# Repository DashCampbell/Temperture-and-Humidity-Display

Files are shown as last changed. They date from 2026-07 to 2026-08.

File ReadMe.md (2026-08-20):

# Temperature & Humidity Display

A basic PCB displaying the temperature and humidity from a sensor to a OLED screen.

* Uses a STM32 microcontroller with SWD.
* Uses FreeRTOS to run tasks concurrently.
* Uses I2C to communicate with the OLED display and sensor.
* Uses PWM to controll a RGB addressable LED.

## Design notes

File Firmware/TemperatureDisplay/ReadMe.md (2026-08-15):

# Potential Improvements

* Use buck converter to drop battery voltage from 9V to 3.3V, more energy efficient

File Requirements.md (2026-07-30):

# Requirements
## General
- Display the temperature
- Display the humidity
- Have led(s) that change color based on temperature

## Hardware
- A temperature sensor
- A humidity sensor
- At least 5 leds
- An LCD Display
- Use a STM32L432KCUx MCU
- **TODO**: Choose a connection type
- Use SWD

### Future Improvements
- Add a battery

## Firmware
- Read temperature data
- Read humidity data
- Render data in LCD display
- Change led color based on temperature

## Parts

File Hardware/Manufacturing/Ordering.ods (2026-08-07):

Reference | Required Qty | Value | URL | Quantity | Cost | Total Cost | Bought
C1,C2 | 2 | 22u | https://www.digikey.ca/en/products/detail/samsung-electro-mechanics/CL21A226KPCLRNC/5961270 | 4 | $0.40 | $1.60 | X
C3,C10 | 2 | 10n | https://www.digikey.ca/en/products/detail/murata-electronics/GCM188R72A103KA37D/1641655 | 4 | $0.10 | $0.40 | X
C4,C5,C6,C7,C11 | 5 | 100n | https://www.digikey.ca/en/products/detail/kyocera-avx/06035C104KAZ2A/1024797 | 10 | $0.10 | $1.00 | X
C8 | 1 | 4u7 | https://www.digikey.ca/en/products/detail/taiyo-yuden/LMK107BJ475KA-T/1004029 | 2 | $0.15 | $0.30 | X
C9 | 1 | 1u | https://www.digikey.ca/en/products/detail/samsung-electro-mechanics/CL10B105KO8NNNC/3886677 | 2 | $0.10 | $0.20 | X
D1 | 1 | WS2812B | https://www.digikey.ca/en/products/detail/sparkfun-electronics/16347/11630204 | 2 | $0.68 | $1.36 | X
FB1 | 1 | 120R |  |  |  | $0.00
J1 | 1 | Power |  | 0 |  | $0.00
J2 | 1 | SSD1306 Display | https://www.amazon.ca/0-96inch-Module-Display-SSD1306-Driver/dp/B0CPZD1GS2 | 1 | $11.58 | $11.58
J3 | 1 | SWD |  | 0 |  | $0.00
LED1,LED2 | 2 | LTST-C170KGKT | https://www.digikey.ca/en/products/detail/liteon/LTST-C170KGKT/386777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 | 4 | $0.19 | $0.76 | X
R1,R2,R4,R5 | 4 | 10k |  |  |  | $0.00
R3 | 1 | 10k |  |  |  | $0.00
SW1 | 1 | SW_Push |  | 0 |  | $0.00
SW2 | 1 | SW_Nidec_CAS-120A1 | https://www.digikey.ca/en/products/detail/nidec-components/CAS-120TA/341661 | 2 | $1.29 | $2.58 | X
U1 | 1 | AMS1117-3.3 |  | 0 |  | $0.00
U2 | 1 | HDC2010YPAR | https://www.digikey.ca/en/products/detail/texas-instruments/HDC2010YPAR/7561364 | 2 | $1.73 | $3.46 | X
U3 | 1 | STM32L432KCU6 | https://www.digikey.ca/en/products/detail/stmicroelectronics/stm32l432kcu6/6132749 | 2 | $5.75 | $11.50 | X
Y1 | 1 | 8MHz Crystal | https://www.digikey.ca/en/products/detail/abracon-llc/ASE-8-000MHZ-L-C-T/1236874 | 2 | $1.30 | $2.60 | X
 |  |  |  |  | Total Parts Cost: | $37.34
Total Ordering Cost
Digikey | $45.30
Amazon | $16.37
JLCPCB | $27.30
Total: | $88.97

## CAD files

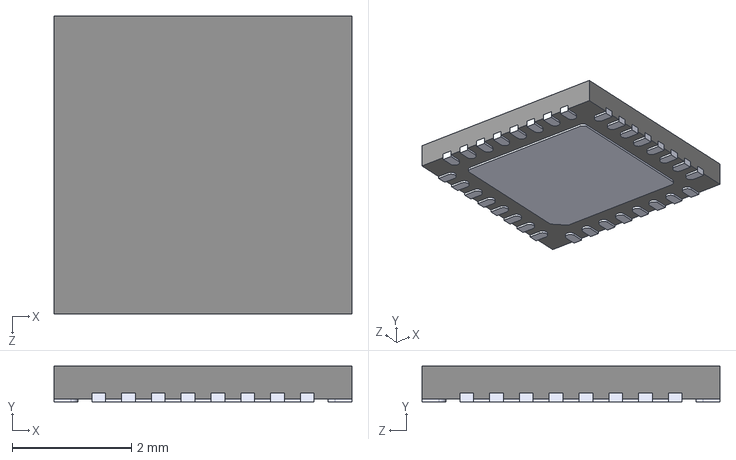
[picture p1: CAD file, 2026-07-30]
Hardware/3D_Models/STM32L432KCU6.step
5.00 x 0.6 x 5.00 mm

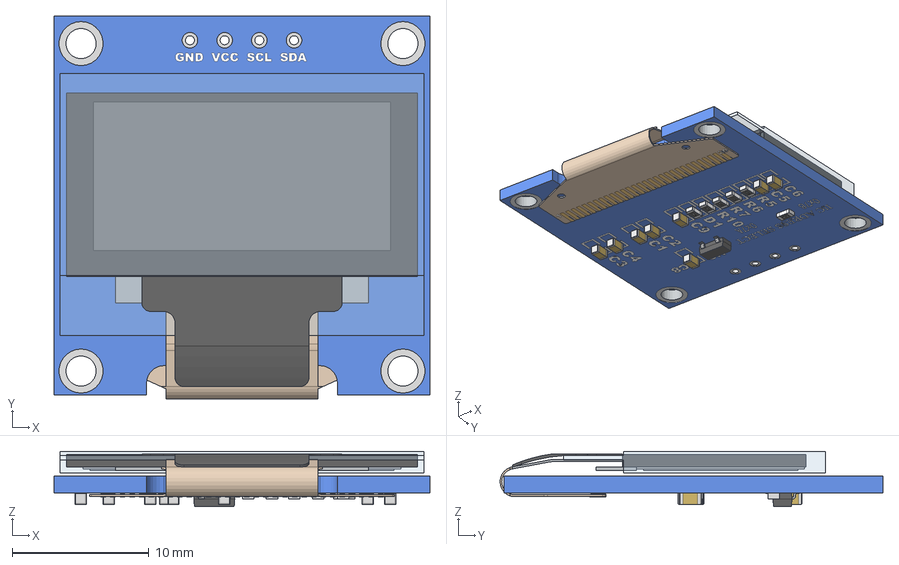
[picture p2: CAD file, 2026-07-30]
Hardware/3D_Models/ER-OLEDM0.96-1-I2C_3D.stp
27.5 x 28.0 x 4.03 mm
0.96 OLED - Board - i2c
0.96 OLED - Glass
0.96 OLED - Flat Reverse
0603 Resistor x 6
SOT-23
0603 Capacitor x 8

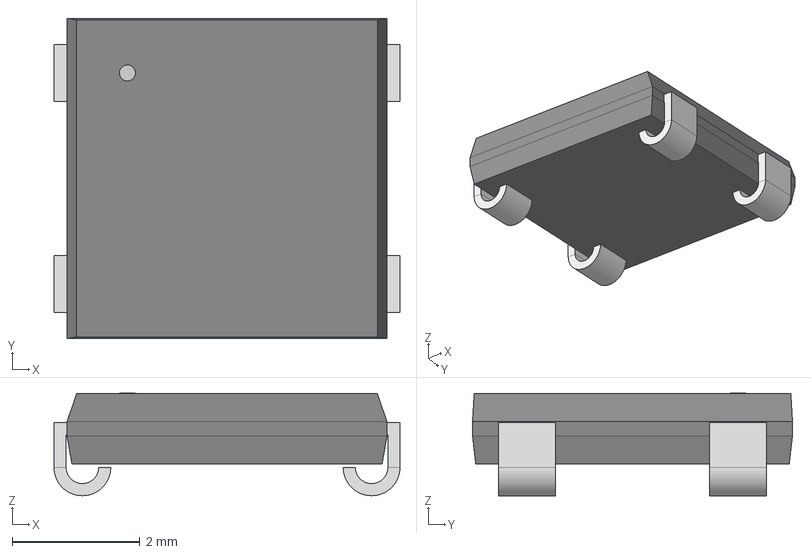
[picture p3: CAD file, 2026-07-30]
Hardware/3D_Models/COM-16347_SPK.step
5.41 x 5.00 x 1.60 mm

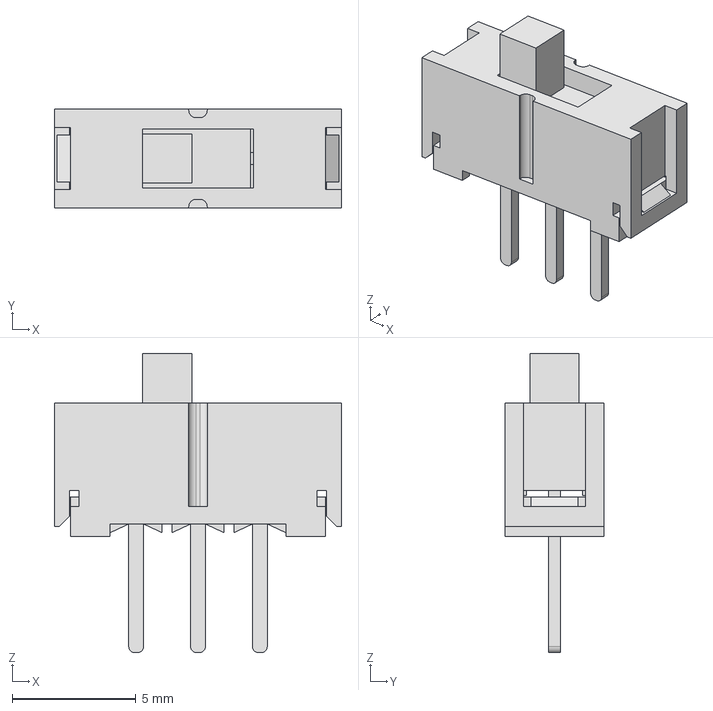
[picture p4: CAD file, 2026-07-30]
Hardware/3D_Models/141_EG1218.stp
11.6 x 4.00 x 12.1 mm

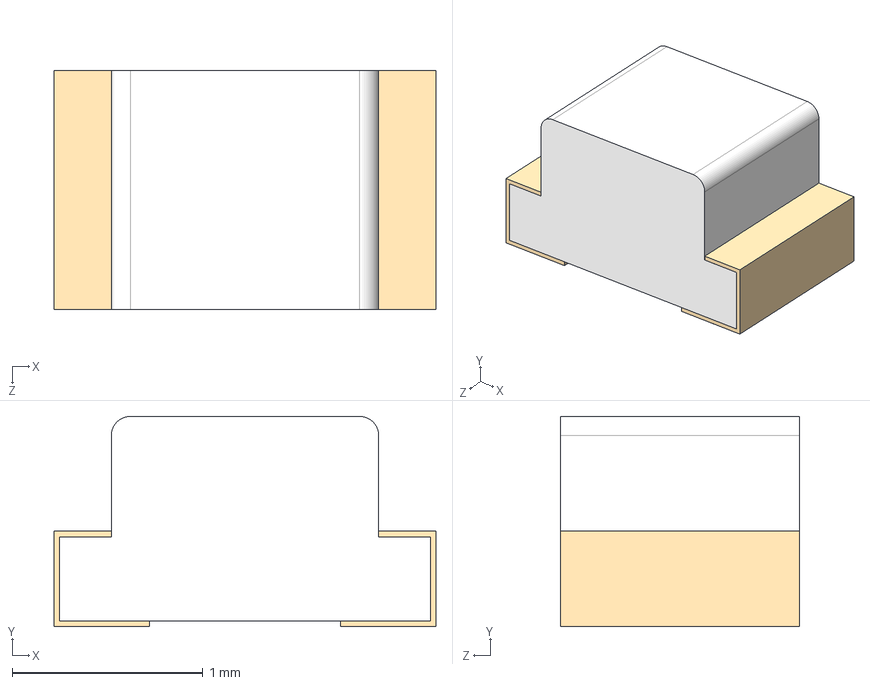
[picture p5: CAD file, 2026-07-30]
Hardware/3D_Models/LTST-C170KGKT.step
2.00 x 1.10 x 1.25 mm

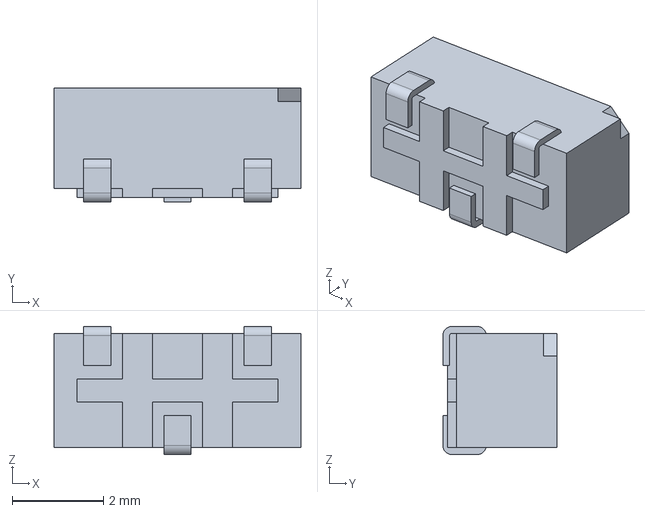
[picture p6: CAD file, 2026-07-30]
Hardware/3D_Models/CAS-120TA.stp
5.40 x 2.50 x 2.80 mm
CAS_c_12A
1 pole_s

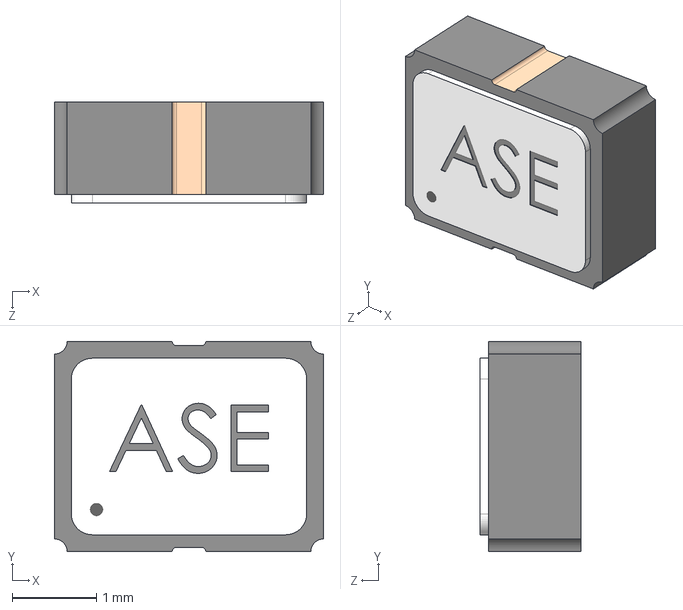
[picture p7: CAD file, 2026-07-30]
Hardware/3D_Models/ASE.STEP
3.20 x 2.50 x 1.20 mm

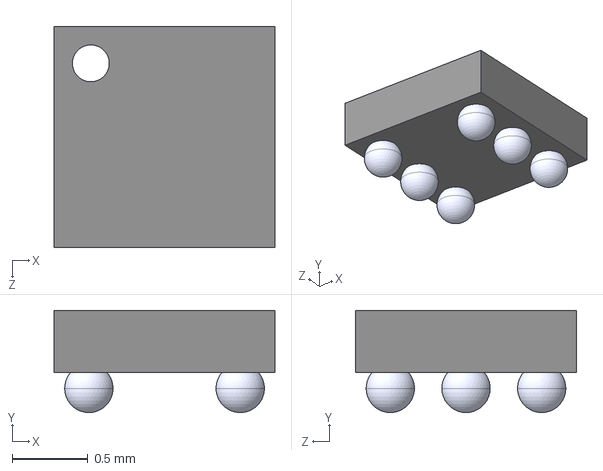
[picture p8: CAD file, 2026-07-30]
Hardware/3D_Models/HDC2010YPAR.step
1.46 x 0.675 x 1.46 mm

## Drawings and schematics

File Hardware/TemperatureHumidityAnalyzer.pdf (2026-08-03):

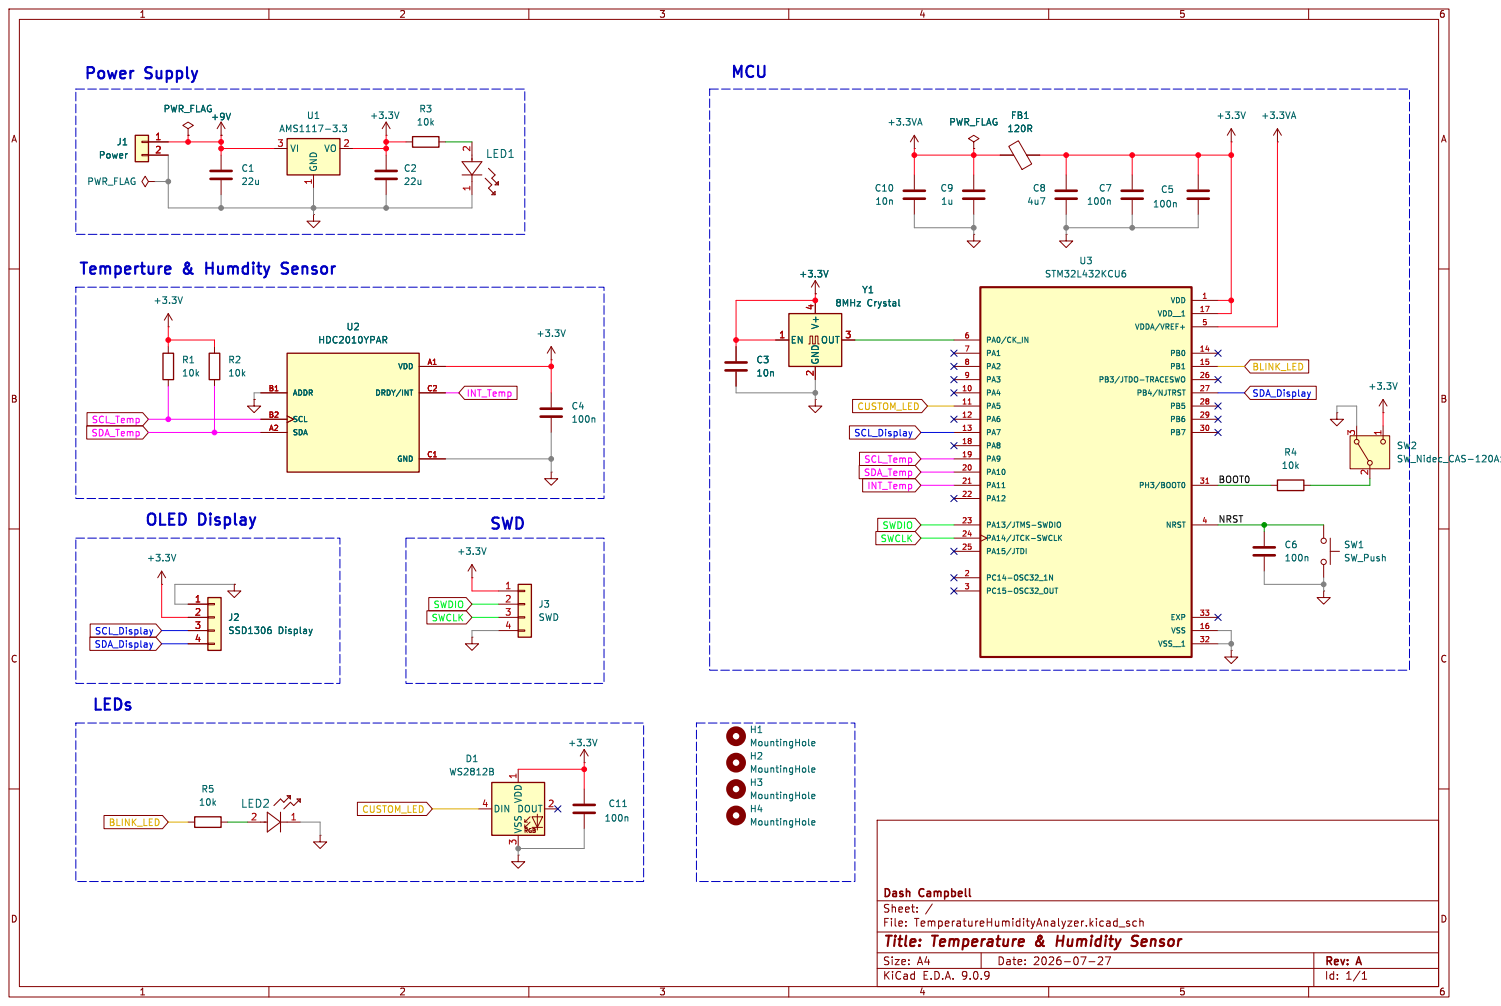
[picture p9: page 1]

Id: 1/1 Title: Temperature & Humidity Sensor File: TemperatureHumidityAnalyzer.kicad_sch Sheet: / Dash Campbell

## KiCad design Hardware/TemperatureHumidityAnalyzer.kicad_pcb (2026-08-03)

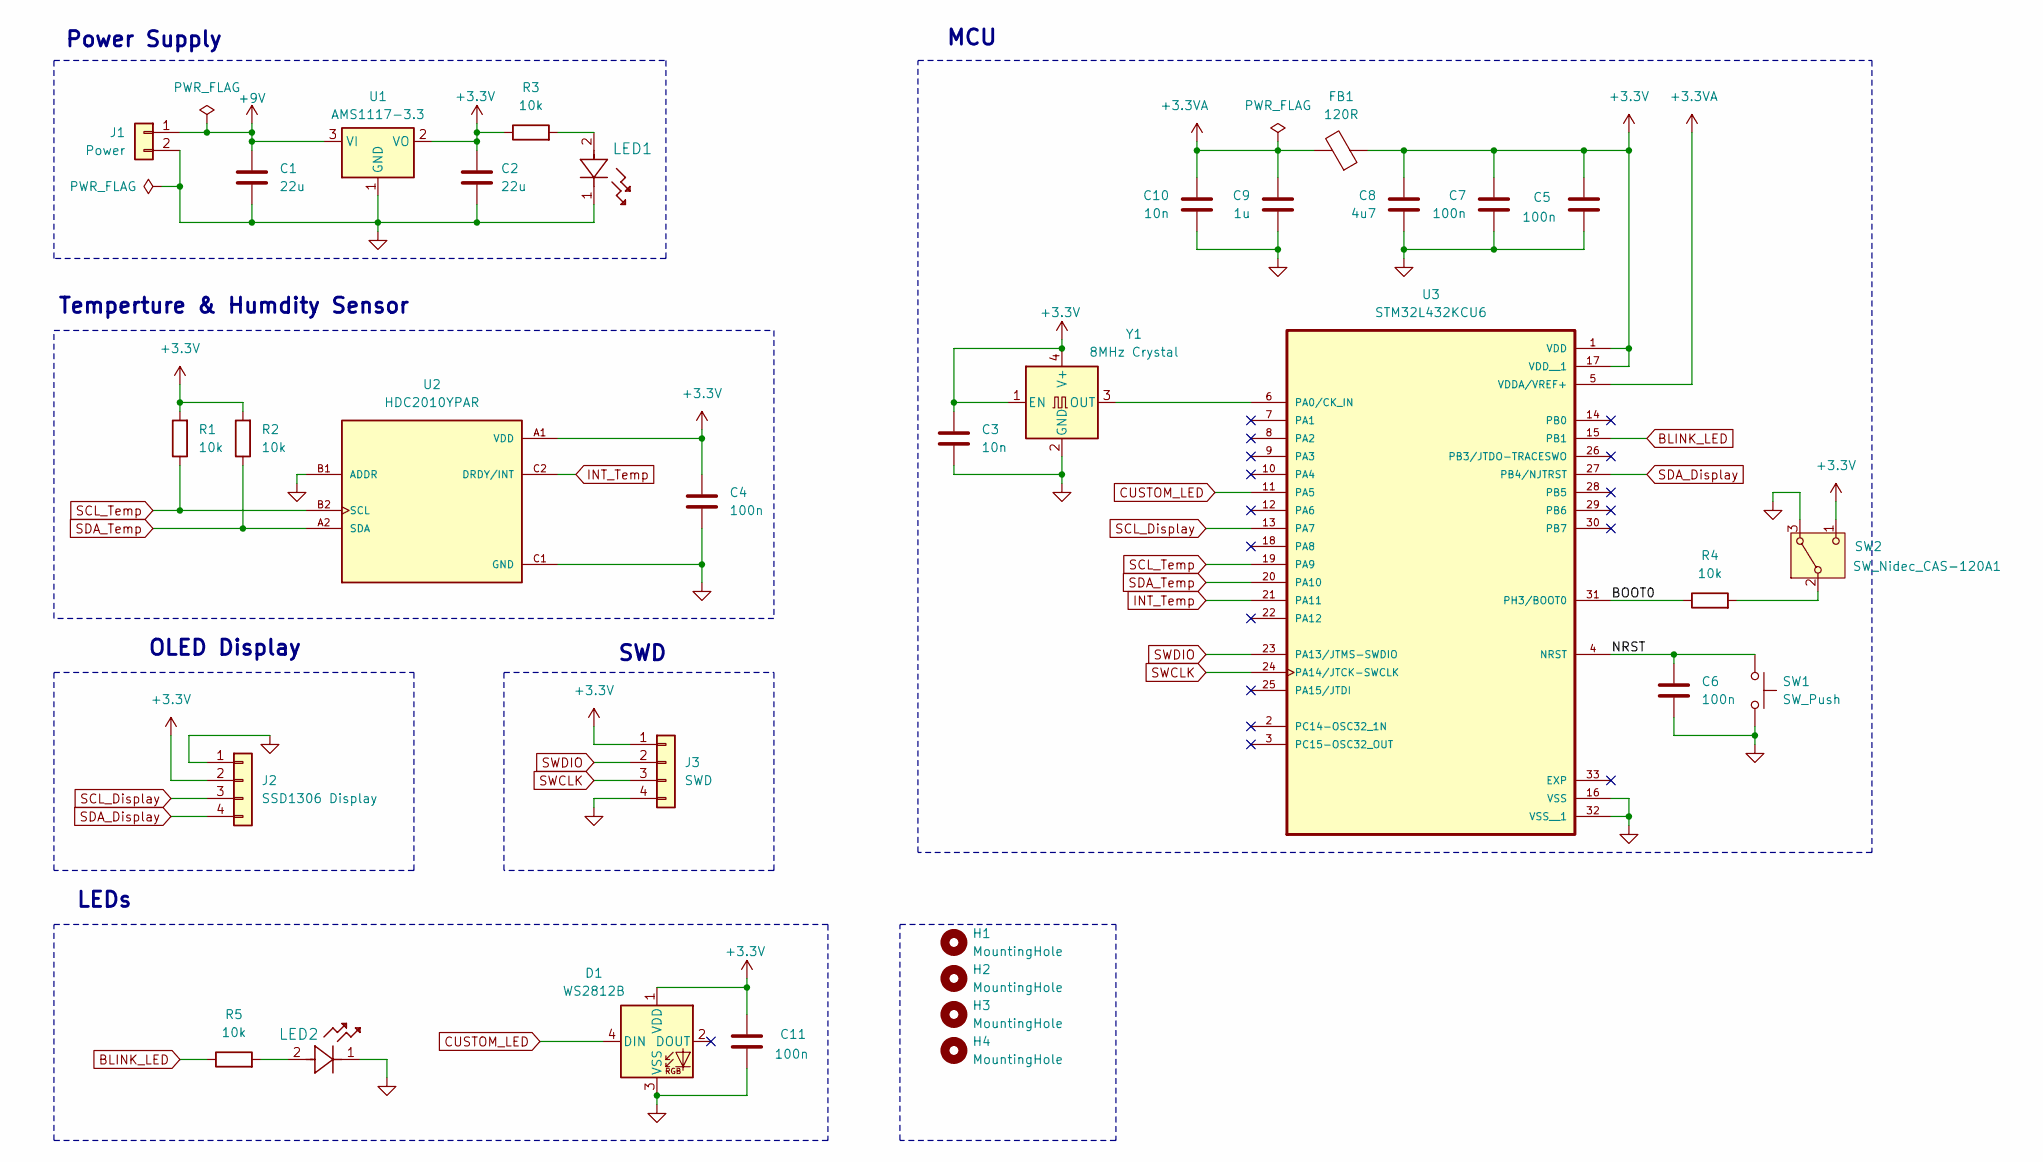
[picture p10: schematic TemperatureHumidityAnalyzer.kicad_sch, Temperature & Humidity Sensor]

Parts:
C1, C2: 22u; C_0805_2012Metric_Pad1.18x1.45mm_HandSolder
C3, C10: 10n; C_0603_1608Metric_Pad1.08x0.95mm_HandSolder
C4, C5, C6, C7, C11: 100n; C_0603_1608Metric_Pad1.08x0.95mm_HandSolder
C8: 4u7; C_0603_1608Metric_Pad1.08x0.95mm_HandSolder
C9: 1u; C_0603_1608Metric_Pad1.08x0.95mm_HandSolder
D1: WS2812B; LED_OPSCO_SK6812_PLCC4_5.0x5.0mm_P3.1mm
FB1: 120R; L_0603_1608Metric_Pad1.05x0.95mm_HandSolder
H1, H2, H3, H4: MountingHole; MountingHole_2.2mm_M2
J1: Power; PinSocket_1x02_P2.54mm_Vertical
J2: SSD1306 Display; SSD1306
J3: SWD; PinHeader_1x04_P2.54mm_Vertical
LED1, LED2: LTST-C170KGKT; LED_LTST-C170KGKT_LTO
R1, R2, R4, R5: 10k; R_0603_1608Metric_Pad0.98x0.95mm_HandSolder
R3: 10k; R_0805_2012Metric_Pad1.20x1.40mm_HandSolder
SW1: SW_Push; SW_PUSH_6mm
SW2: SW_Nidec_CAS-120A1; Nidec_Copal_CAS-120A
U1: AMS1117-3.3; SOT-223-3_TabPin2
U2: HDC2010YPAR; BGA6C100X50P2X3_HDC2010YPAR; PARTREV C
U3: STM32L432KCU6; PARTREV 3
Y1: 8MHz Crystal; Oscillator_SMD_EuroQuartz_XO32-4Pin_3.2x2.5mm

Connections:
+3.3V: C2.1, C3.1, C4.1, C5.1, C7.1, C8.1, C11.1, D1.1 (VDD), FB1.1, J2.2, J3.1, R1.2, R2.2, R3.1, SW2.1 (C), U1.2 (VO), U2.A1 (VDD), U3.1 (VDD), U3.17 (VDD__1), Y1.1 (EN), Y1.4 (V+)
+3.3VA: C9.1, C10.1, FB1.2, U3.5 (VDDA/VREF+)
+9V: C1.1, J1.1, U1.3 (VI)
/BOOT0: R4.1, U3.31 (PH3/BOOT0)
/NRST: C6.1, SW1.1, U3.4 (NRST)
BLINK_LED: R5.1, U3.15 (PB1)
CUSTOM_LED: D1.4 (DIN), U3.11 (PA5)
GND: C1.2, C2.2, C3.2, C4.2, C5.2, C6.2, C7.2, C8.2, C9.2, C10.2, C11.2, D1.3 (VSS), J1.2, J2.1, J3.4, LED1.1, LED2.1, SW1.2, SW2.3 (A), U1.1 (GND), U2.B1 (ADDR), U2.C1 (GND), U3.16 (VSS), U3.32 (VSS__1), Y1.2 (GND)
INT_Temp: U2.C2 (DRDY/INT), U3.21 (PA11)
unnamed: LED1.2, R3.2
unnamed: LED2.2, R5.2
unnamed: R4.2, SW2.2 (B)
unnamed: U3.6 (PA0/CK_IN), Y1.3 (OUT)
SCL_Display: J2.3, U3.13 (PA7)
SCL_Temp: R1.1, U2.B2 (SCL), U3.19 (PA9)
SDA_Display: J2.4, U3.27 (PB4/NJTRST)
SDA_Temp: R2.1, U2.A2 (SDA), U3.20 (PA10)
SWCLK: J3.3, U3.24 (PA14/JTCK-SWCLK)
SWDIO: J3.2, U3.23 (PA13/JTMS-SWDIO)

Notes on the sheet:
OLED Display
Power Supply
SWD
Temperture & Humdity Sensor
LEDs
MCU

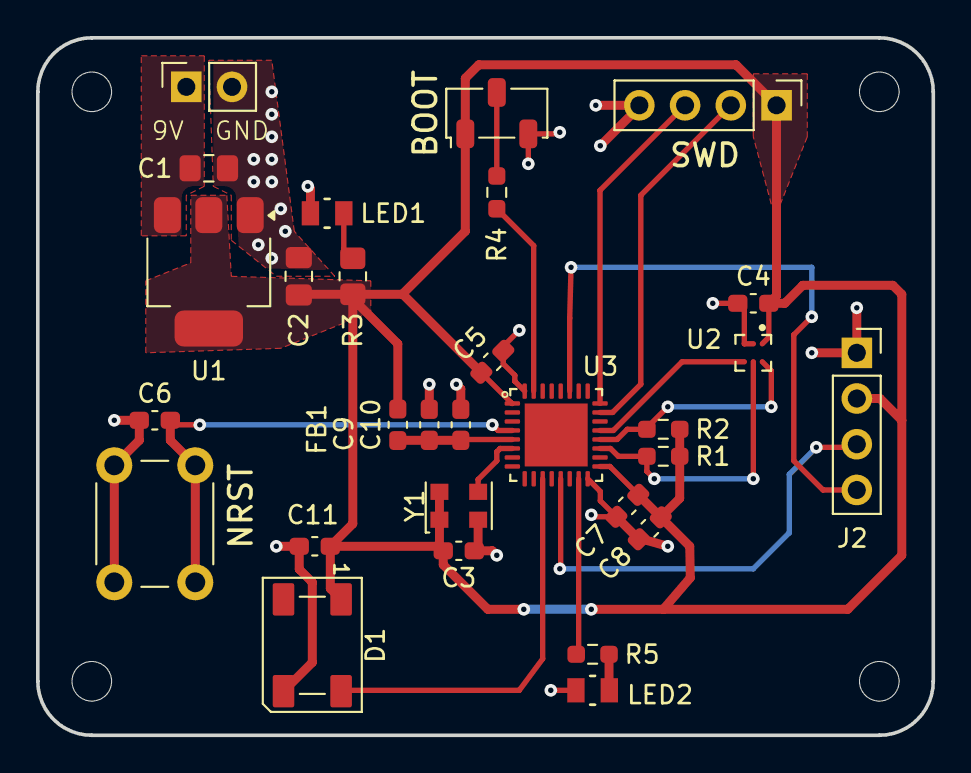
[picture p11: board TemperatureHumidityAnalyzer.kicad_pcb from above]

Board: 2 copper layers, 49.8 x 38.8 mm, 33 parts (0 on the bottom side), 19 nets.

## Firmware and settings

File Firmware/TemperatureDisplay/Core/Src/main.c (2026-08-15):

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
/* Includes ------------------------------------------------------------------*/
#include "main.h"
#include "cmsis_os.h"

/* USER CODE BEGIN Includes */
#include "ssd1306_fonts.h"
#include "ssd1306.h"
#include "hdc2010.h"
#include "ws2812b.h"
#include <stdio.h>
// I2C api
// https://dev.st.com/stm32cube-docs/stm32u5-hal2/2.0.0-beta.1.1/docs/drivers/hal_drivers/i2c/hal_i2c_apis.html

/* USER CODE END Includes */

typedef StaticTask_t osStaticThreadDef_t;
typedef StaticQueue_t osStaticMessageQDef_t;
typedef StaticEventGroup_t osStaticEventGroupDef_t;
/* USER CODE BEGIN PD */

// FreeRTOS Events
#define SENSOR_READY 0x01

/* USER CODE END PD */

I2C_HandleTypeDef hi2c1;
I2C_HandleTypeDef hi2c3;

TIM_HandleTypeDef htim2;
DMA_HandleTypeDef hdma_tim2_ch1;

/* Definitions for defaultTask */
osThreadId_t defaultTaskHandle;
uint32_t defaultTaskBuffer[ 128 ];
osStaticThreadDef_t defaultTaskControlBlock;
const osThreadAttr_t defaultTask_attributes = {
  .name = "defaultTask",
  .cb_mem = &defaultTaskControlBlock,
  .cb_size = sizeof(defaultTaskControlBlock),
  .stack_mem = &defaultTaskBuffer[0],
  .stack_size = sizeof(defaultTaskBuffer),
  .priority = (osPriority_t) osPriorityNormal,
};
/* Definitions for sensorTask */
osThreadId_t sensorTaskHandle;
uint32_t sensorTaskBuffer[ 512 ];
osStaticThreadDef_t sensorTaskControlBlock;
const osThreadAttr_t sensorTask_attributes = {
  .name = "sensorTask",
  .cb_mem = &sensorTaskControlBlock,
  .cb_size = sizeof(sensorTaskControlBlock),
  .stack_mem = &sensorTaskBuffer[0],
  .stack_size = sizeof(sensorTaskBuffer),
  .priority = (osPriority_t) osPriorityNormal,
};
/* Definitions for displayTask */
osThreadId_t displayTaskHandle;
uint32_t displayTaskBuffer[ 3000 ];
osStaticThreadDef_t displayTaskControlBlock;
const osThreadAttr_t displayTask_attributes = {
  .name = "displayTask",
  .cb_mem = &displayTaskControlBlock,
  .cb_size = sizeof(displayTaskControlBlock),
  .stack_mem = &displayTaskBuffer[0],
  .stack_size = sizeof(displayTaskBuffer),
  .priority = (osPriority_t) osPriorityBelowNormal,
};
/* Definitions for ledTask */
osThreadId_t ledTaskHandle;
uint32_t ledTaskBuffer[ 256 ];
osStaticThreadDef_t ledTaskControlBlock;
const osThreadAttr_t ledTask_attributes = {
  .name = "ledTask",
  .cb_mem = &ledTaskControlBlock,
  .cb_size = sizeof(ledTaskControlBlock),
  .stack_mem = &ledTaskBuffer[0],
  .stack_size = sizeof(ledTaskBuffer),
  .priority = (osPriority_t) osPriorityLow,
};
/* Definitions for humidityValue */
osMessageQueueId_t humidityValueHandle;
uint8_t humidityValueBuffer[ 10 * sizeof( uint8_t ) ];
osStaticMessageQDef_t humidityValueControlBlock;
const osMessageQueueAttr_t humidityValue_attributes = {
  .name = "humidityValue",
  .cb_mem = &humidityValueControlBlock,
  .cb_size = sizeof(humidityValueControlBlock),
  .mq_mem = &humidityValueBuffer,
  .mq_size = sizeof(humidityValueBuffer)
};
/* Definitions for temperatureValue */
osMessageQueueId_t temperatureValueHandle;
uint8_t temperatureValueBuffer[ 10 * sizeof( uint8_t ) ];
osStaticMessageQDef_t temperatureValueControlBlock;
const osMessageQueueAttr_t temperatureValue_attributes = {
  .name = "temperatureValue",
  .cb_mem = &temperatureValueControlBlock,
  .cb_size = sizeof(temperatureValueControlBlock),
  .mq_mem = &temperatureValueBuffer,
  .mq_size = sizeof(temperatureValueBuffer)
};
/* Definitions for sensorEvent */
osEventFlagsId_t sensorEventHandle;
osStaticEventGroupDef_t sensorEventControlBlock;
const osEventFlagsAttr_t sensorEvent_attributes = {
  .name = "sensorEvent",
  .cb_mem = &sensorEventControlBlock,
  .cb_size = sizeof(sensorEventControlBlock),
};
void SystemClock_Config(void);
static void MX_GPIO_Init(void);
static void MX_DMA_Init(void);
static void MX_I2C1_Init(void);
static void MX_I2C3_Init(void);
static void MX_TIM2_Init(void);
void StartDefaultTask(void *argument);
void StartSensorTask(void *argument);
void StartDisplayTask(void *argument);
void StartLedTask(void *argument);

/* USER CODE BEGIN 0 */
void HAL_TIM_PWM_PulseFinishedCallback(TIM_HandleTypeDef *htim) 
{
  WS2812_Callback();
}

/* Handle Sensor Interrupt */
void HAL_GPIO_EXTI_Callback(uint16_t GPIO_Pin)
{
  osEventFlagsSet(sensorEventHandle, SENSOR_READY);
}
/* USER CODE END 0 */

/**
  * @brief  The application entry point.
  * @retval int
  */
int main(void)
{

  /* MCU Configuration--------------------------------------------------------*/

  /* Reset of all peripherals, Initializes the Flash interface and the Systick. */
  HAL_Init();

  /* Configure the system clock */
  SystemClock_Config();

  /* USER CODE BEGIN SysInit */

  // Enable debugging in Low-Power modes
  HAL_DBGMCU_EnableDBGSleepMode();
  HAL_DBGMCU_EnableDBGStopMode();
  HAL_DBGMCU_EnableDBGStandbyMode();
  
  /* USER CODE END SysInit */

  /* Initialize all configured peripherals */
  MX_GPIO_Init();
  MX_DMA_Init();
  MX_I2C1_Init();
  MX_I2C3_Init();
  MX_TIM2_Init();
  /* USER CODE BEGIN 2 */

  // Initialize Addressable LED
  WS2812_Init();

  /* USER CODE END 2 */

  /* Init scheduler */
  osKernelInitialize();

  /* USER CODE BEGIN RTOS_MUTEX */
  /* add mutexes, ... */
  /* USER CODE END RTOS_MUTEX */

  /* USER CODE BEGIN RTOS_SEMAPHORES */
  /* add semaphores, ... */
  /* USER CODE END RTOS_SEMAPHORES */

  /* USER CODE BEGIN RTOS_TIMERS */
  /* start timers, add new ones, ... */
  /* USER CODE END RTOS_TIMERS */

  /* Create the queue(s) */
  /* creation of humidityValue */
  humidityValueHandle = osMessageQueueNew (10, sizeof(uint8_t), &humidityValue_attributes);

  /* creation of temperatureValue */
  temperatureValueHandle = osMessageQueueNew (10, sizeof(uint8_t), &temperatureValue_attributes);

  /* USER CODE BEGIN RTOS_QUEUES */
  /* add queues, ... */
  /* USER CODE END RTOS_QUEUES */

  /* Create the thread(s) */
  /* creation of defaultTask */
  defaultTaskHandle = osThreadNew(StartDefaultTask, NULL, &defaultTask_attributes);

  /* creation of sensorTask */
  sensorTaskHandle = osThreadNew(StartSensorTask, NULL, &sensorTask_attributes);

  /* creation of displayTask */
  displayTaskHandle = osThreadNew(StartDisplayTask, NULL, &displayTask_attributes);

  /* creation of ledTask */
  ledTaskHandle = osThreadNew(StartLedTask, NULL, &ledTask_attributes);

  /* USER CODE BEGIN RTOS_THREADS */
  /* add threads, ... */
  /* USER CODE END RTOS_THREADS */

  /* Create the event(s) */
  /* creation of sensorEvent */
  sensorEventHandle = osEventFlagsNew(&sensorEvent_attributes);

  /* Start scheduler */
  osKernelStart();

  /* We should never get here as control is now taken by the scheduler */

  /* Infinite loop */
  /* USER CODE BEGIN WHILE */
  while (1)
  {
    /* USER CODE END WHILE */

    /* USER CODE BEGIN 3 */
  }
  /* USER CODE END 3 */
}

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
/* USER CODE BEGIN Header_StartDefaultTask */
/**
  * @brief  Function implementing the defaultTask thread.
  * @param  argument: Not used
  * @retval None
  */
/* USER CODE END Header_StartDefaultTask */
void StartDefaultTask(void *argument)
{
  /* USER CODE BEGIN 5 */

  // For now DefaultTask is unused
  osThreadTerminate(defaultTaskHandle);

  /* Infinite loop */
  for(;;)
  {
    osDelay(1000);
  }

  /* USER CODE END 5 */
}

/* USER CODE BEGIN Header_StartSensorTask */
/**
* @brief Function implementing the sensorTask thread.
* @param argument: Not used
* @retval None
*/
/* USER CODE END Header_StartSensorTask */
void StartSensorTask(void *argument)
{
  /* USER CODE BEGIN StartSensorTask */
  WS2812_SetColor(0,0, 5, 0);
  WS2812_Update();
  osDelay(1000);
  
  WS2812_SetColor(0,5, 0, 0);
  WS2812_Update();
  osDelay(1000);
  
  WS2812_SetColor(0,0, 0, 5);
  WS2812_Update();
  osDelay(1000);

  if (hdc2010_init() != HAL_OK)
  {
    // log error
    WS2812_SetColor(0,3, 0, 0);
    WS2812_Update();
  }
  
  uint8_t humidity = 1;
  uint8_t temperature = 1;
  
  /* Infinite loop */
  for(;;)
  {
    // 1800
    uint32_t task1Stack = osThreadGetStackSpace(sensorTaskHandle);

    // Wait for interrupt signal from HDC2010 before retreiving data
    // osEventFlagsWait(sensorEventHandle, SENSOR_READY, osFlagsWaitAll, osWaitForever);

    // // Retreive data from sensor
    // if (hdc2010_read_temperature_humidity(&temperature, &humidity) != HAL_OK)
    // {
    //   // log error
    // }

    // Put temperature and humidity values in queues
    osMessageQueuePut(humidityValueHandle, &humidity, 0, 0);
    osMessageQueuePut(temperatureValueHandle, &temperature, 0, 0);

    ++humidity;
    ++temperature;

    osDelay(1000);
  }
  /* USER CODE END StartSensorTask */
}

/* USER CODE BEGIN Header_StartDisplayTask */
/**
* @brief Function implementing the displayTask thread.
* @param argument: Not used
* @retval None
*/
/* USER CODE END Header_StartDisplayTask */
void StartDisplayTask(void *argument)
{
  /* USER CODE BEGIN StartDisplayTask */
  // Initialize display
  ssd1306_Init();
  ssd1306_Fill(Black);
  ssd1306_WriteString("Starting...", Font_11x18, White);
  ssd1306_UpdateScreen();
  // 
  // WS2812_SetColor(0,3, 0, 0);
  // WS2812_Update();

  uint8_t humidity = 0;
  uint8_t temperature = 0;

  char cHumidity[10] = {0};
  char cTemperature[10] = {0};

  osDelay(1000);

  /* Infinite loop */
  for(;;)
  {
    // 11528
    uint32_t task2Stack = osThreadGetStackSpace(displayTaskHandle);

    // Retreive data from queue
    // If queue is empty, use previous value
    osStatus_t _h = osMessageQueueGet(humidityValueHandle, &humidity, NULL, 0);
    osStatus_t _t = osMessageQueueGet(temperatureValueHandle, &temperature, NULL, 0);

    // Convert values to string
    snprintf(cHumidity, sizeof(cHumidity), "%d", humidity);
    snprintf(cTemperature, sizeof(cTemperature), "%d", temperature);

    // Render Values
    ssd1306_Fill(Black);
    ssd1306_SetCursor(0, 0);
    ssd1306_WriteString("T: ", Font_11x18, White);
    ssd1306_WriteString(cTemperature, Font_11x18, White);
    ssd1306_WriteString(" C", Font_11x18, White);
    
    ssd1306_SetCursor(0, 20);
    ssd1306_WriteString("H: ", Font_11x18, White);
    ssd1306_WriteString(cHumidity, Font_11x18, White);
    ssd1306_WriteString(" %", Font_11x18, White);
    ssd1306_UpdateScreen();

    // Set color of WS2818B LED
    // WS2812_SetColor(0,0, 0, 1);
    // WS2812_Update();
    

    osDelay(1000);
  }
  /* USER CODE END StartDisplayTask */
}

/* USER CODE BEGIN Header_StartLedTask */
/**
* @brief Function implementing the ledTask thread.
* @param argument: Not used
* @retval None
*/
/* USER CODE END Header_StartLedTask */
void StartLedTask(void *argument)
{
  /* USER CODE BEGIN StartLedTask */
  /* Infinite loop */
  for(;;)
  {
    // 872
    uint32_t task3Stack = osThreadGetStackSpace(ledTaskHandle);
    HAL_GPIO_TogglePin(BLINK_LED_GPIO_Port, BLINK_LED_Pin);
    osDelay(1000);
  }
  /* USER CODE END StartLedTask */
}

/**
  * @brief  Period elapsed callback in non blocking mode
  * @note   This function is called  when TIM7 interrupt took place, inside
  * HAL_TIM_IRQHandler(). It makes a direct call to HAL_IncTick() to increment
  * a global variable "uwTick" used as application time base.
  * @param  htim : TIM handle
  * @retval None
  */
void HAL_TIM_PeriodElapsedCallback(TIM_HandleTypeDef *htim)
{
  if (htim->Instance == TIM7)
  {
    HAL_IncTick();
  }
}

/**
  * @brief  This function is executed in case of error occurrence.
  * @retval None
  */
void Error_Handler(void)
{
  /* USER CODE BEGIN Error_Handler_Debug */
  /* User can add his own implementation to report the HAL error return state */
  __disable_irq();
  while (1)
  {
  }
  /* USER CODE END Error_Handler_Debug */
}
#ifdef USE_FULL_ASSERT
/**
  * @brief  Reports the name of the source file and the source line number
  *         where the assert_param error has occurred.
  * @param  file: pointer to the source file name
  * @param  line: assert_param error line source number
  * @retval None
  */
void assert_failed(uint8_t *file, uint32_t line)
{
  /* USER CODE BEGIN 6 */
  /* User can add his own implementation to report the file name and line number,
     ex: printf("Wrong parameters value: file %s on line %d\r\n", file, line) */
  /* USER CODE END 6 */
}
#endif /* USE_FULL_ASSERT */

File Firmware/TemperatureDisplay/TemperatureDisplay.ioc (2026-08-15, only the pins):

Mcu.UserName=STM32L432KCUx
PA0.Signal=RCC_CK_IN
PA10.GPIO_Label=SDA_TEMP
PA10.Signal=I2C1_SDA
PA11.GPIO_Label=INT_TEMP
PA11.Signal=GPXTI11
PA5.GPIO_Label=PWM_LED
PA5.Signal=S_TIM2_CH1
PA7.GPIO_Label=SCL_DISPLAY
PA7.Signal=I2C3_SCL
PA9.GPIO_Label=SCL_TEMP
PA9.Signal=I2C1_SCL
PB1.GPIO_Label=BLINK_LED
PB1.Signal=GPIO_Output

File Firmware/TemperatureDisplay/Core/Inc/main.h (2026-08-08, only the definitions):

#define PWM_LED_Pin GPIO_PIN_5
#define PWM_LED_GPIO_Port GPIOA
#define SCL_DISPLAY_Pin GPIO_PIN_7
#define SCL_DISPLAY_GPIO_Port GPIOA
#define BLINK_LED_Pin GPIO_PIN_1
#define BLINK_LED_GPIO_Port GPIOB
#define SCL_TEMP_Pin GPIO_PIN_9
#define SCL_TEMP_GPIO_Port GPIOA
#define SDA_TEMP_Pin GPIO_PIN_10
#define SDA_TEMP_GPIO_Port GPIOA
#define INT_TEMP_Pin GPIO_PIN_11
#define INT_TEMP_GPIO_Port GPIOA
#define INT_TEMP_EXTI_IRQn EXTI15_10_IRQn
#define SDA_DISPLAY_Pin GPIO_PIN_4
#define SDA_DISPLAY_GPIO_Port GPIOB

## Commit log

2026-07-30 Create schematic and PCB layout
    [141_EG1218.stp, ASE.STEP, CAS-120TA.stp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]
2026-07-30 Add mounting holes
    [TemperatureHumidityAnalyzer.kicad_pcb, TemperatureHumidityAnalyzer.kicad_sch]
2026-08-01 Finish pcb layout
    [TemperatureHumidityAnalyzer.kicad_pcb]
2026-08-01 Route pcb
    [TemperatureHumidityAnalyzer.kicad_pcb]
2026-08-03 Generate manufacturing files
    [Ordering.ods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]
2026-08-03 Untrack kicad backup files
    [Ordering.csv, TemperatureHumidityAnalyzer.csv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]
2026-08-06 Add OLED driver library
2026-08-07 Add Sensor Driver
2026-08-07 Add Ordering document
    [Ordering.ods]
2026-08-08 Add interrupt handling
2026-08-10 Add WS2812B driver
2026-08-14 Render temperature and humidity

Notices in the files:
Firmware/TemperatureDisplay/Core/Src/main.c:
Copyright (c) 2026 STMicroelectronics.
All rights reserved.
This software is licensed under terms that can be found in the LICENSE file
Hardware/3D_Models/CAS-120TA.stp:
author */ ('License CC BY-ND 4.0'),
